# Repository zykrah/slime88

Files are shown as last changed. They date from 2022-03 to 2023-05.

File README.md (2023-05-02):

# Slime88 TKL PCB
 A F13 TKL Multi-Layout Hotswap H88-Compat Type-C PCB, designed in KiCAD 6.0.

**This board has now been prototyped! See IRL images below.**

> NOTE: Below images may be outdated.

Renders (KiCAD):





IRL images of rev1 protos:







## Features
- Fits the h88(c) standard (confirmed working in a KFE CE, should fit F13 frog)
- Uses the RP2040 MCU (new), with 16MB of external flash
- Uses Kailh Hotswap Sockets
- Added anti-shearing to the hotswap sockets
- Holes of hotswap socket holes are plated, you can still solder in a switch, should a hotswap socket ever shear off for whatever reason
- Multi-layout (see below)
- Removable USB-C connector, as well as a JST connector for [Unified Daughterboard](https://github.com/ai03-2725/Unified-Daughterboard) support (for F13 TKL boards that are compatible with the daughterboard version of the h88c)
- Has cutouts for a gummy o-ring mount (Same as the hineybush h88c pcb, for boards such as the Freebird TKL or TGR Jane V2 CE)
- BOOT pins/header for getting into bootloader (short the pins while plugging in) if [bootmagic](https://github.com/qmk/qmk_firmware/blob/master/docs/feature_bootmagic.md) isn't available . Acessible from both sides of the PCB, even when PCB is built in a keyboard. Just remove the **END key/switch** to access it.
- SWD header for debugging
- Has unused MCU GPIO pins broken out
- ESD chip (SRV05-4) to prevent damage from electrostatic discharge
- Polyfuse to prevent overcurrent
- Optimized for manufacturing and assembly with JLCPCB
- Bonus: Curved traces and teardrops

> Also, `Sleep-Lib` is just the library by [Sleepdealer](https://github.com/Sleepdealr), used in his [RP2040 Design guide](https://github.com/Sleepdealr/RP2040-designguide).

## Firmware
~~As of writing, the board runs the rp2040 branch/fork of vial-qmk. I will update this to use the official QMK implementation of RP2040 when it releases.~~ ~~UPDATE: RP2040 support has recently made it into QMK's `develop` branch. It will be fully merged to `master` by Q3 this year. Until then, the official maintainer of vial doesn't intend to merge those changes into their vial repo either, so I have made my own fork for the boards. When vial-qmk is officially updated to use QMK's implementiation of the RP2040, I will update this page once again linking to that, assuming I get the board merged into the official repo too.~~

You can find the up-to-date VIAL firmware [here](https://github.com/zykrah/vial-qmk/tree/vial-stable-zykrah/keyboards/zykrah/slime88). 

UPDATE: The board is now also in [qmk master](https://github.com/qmk/qmk_firmware/tree/master/keyboards/zykrah/slime88). (This particular version will only be VIA compatible). It should automatically be detected in VIA.



## WIP/Ideas
- Spare components on the board (i.e. diodes)
- Add physical reset switch (you currently have to short the pins on the SWD header manually)
- Add physical boot switch (you currently have to short the BOOT pins manually)
- Version with flex cuts (Already done but removed for acoustic reasons. See the board at [this point in time](https://github.com/zykrah/slime88/commit/3de3e59620d77a87f4beb085508b7e4e2e0daaf5))
- Update silkscreen graphics
- Add more layout indicators on the top silkscreen of the pcb
- Do something more special with USB shield/ground connection (currently shield is connected straight to ground)
- Move ESD chip to before fuse
- ~~Also breakout 3v3 and 5v on the pin breakout~~ Thanks [@vinorodrigues](https://github.com/vinorodrigues)!

## Multi-Layout Support

> NOTE: ANSI/ISO support works a little bit specially, either combination is soldered in at a time to ensure minimal R3 Cherry profile interference, and avoid having to rotate hotswap sockets 90 degrees to east/west orientation. See second image below.





## Removable USB C Port

Uses mousebites. Strength/functionality is untested.



## How to Manufacture the PCBs (JLCPCB)
~~I would personally use [this plugin](https://github.com/Bouni/kicad-jlcpcb-tools).~~

~~All components should be basic components, apart from the MCU, fuse, and JST connector (extended).~~

~~JLC also does have [kailh hotswap sockets](https://jlcpcb.com/parts/componentSearch?isSearch=true&searchTxt=C2803348) (extended) in its parts library, but you should be very careful with the ANSI/ISO multilayout support. In the BOM, only include either desired combination of sockets (or none of them, and hand solder in the ones you want).~~

The manufacturing files (JLCPCBA specific) have been added to the repo, you need to choose betweeen ANSI or ISO enter/pipe hotswap sockets being soldered by default.

You may want to consider generating the manufacturing files for yourself. I have not fully tested the ones that are currently in the repo.

> **NOTE: As the USB C connector is top-mounted (all other components are bottom mounted), as of writing, JLCPCB will charge extra to assemble the USB C connector (Standard assembly, both sides). You will likely have to hand solder it if you don't want to pay too much. Otherwise, seek out a proper PCB manufacturer (which will require further experience/knowledge).**

## Silkscreen
For the non-weebs, the silkscreen is based on Rimuru Tempest



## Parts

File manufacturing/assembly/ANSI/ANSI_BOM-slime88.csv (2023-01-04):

Comment | Designator | Footprint | LCSC
1k | R4,R5 | R_0402_1005Metric | C11702
JST-SH-4P | J3 | JST_SH_SM04B-SRSS-TB_1x04-1MP_P1.00mm_Horizontal | C145956
100nF | C10,C11,C12,C17,C2,C3,C6,C7,C8,C9 | C_0402_1005Metric | C1525
10uF | C4 | C_0402_1005Metric | C15525
22pF | C15,C16 | C_0402_1005Metric | C1555
USB_C | J1 | USB_C_Receptacle_HRO_TYPE-C-31-M-12 | C165948
RP2040 | U2 | RP2040-QFN-56 | C2040
27R | R2,R3 | R_0603_1608Metric | C25190
10k | R1 | R_0402_1005Metric | C25744
5.1k | R6,R7 | R_0402_1005Metric | C25905
? | SW1,SW10,SW100,SW101,SW102,SW103,SW104,SW11,SW12,SW13,SW14,SW15,SW16,SW17,SW18,SW19,SW2,SW20,SW21,SW22,SW23,SW24,SW25,SW26,SW27,SW28,SW29,SW3,SW30,SW31,SW32,SW33,SW34,SW35,SW36,SW37,SW38,SW39,SW4,SW40,SW41,SW42,SW43,SW44,SW45,SW46,SW47,SW48,SW49,SW5,SW50,SW52,SW53,SW54,SW55,SW56,SW57,SW58,SW59,SW6,SW60,SW61,SW62,SW63,SW64,SW65,SW66,SW67,SW69,SW7,SW70,SW71,SW72,SW73,SW74,SW75,SW76,SW77,SW78,SW79,SW8,SW80,SW81,SW82,SW83,SW84,SW85,SW86,SW87,SW88,SW89,SW9,SW90,SW91,SW92,SW93,SW94,SW95,SW96,SW97,SW98,SW99 | SW_MX_HS_1u | C5156480
1uF | C1,C13,C14,C5 | C_0402_1005Metric | C52923
XC6206 | U1 | SOT-23 | C5446
500mA | F1 | Fuse_1206_3216Metric | C70076
D | D1,D10,D11,D12,D13,D14,D15,D16,D17,D18,D19,D2,D20,D21,D22,D23,D24,D25,D26,D27,D28,D29,D3,D30,D31,D32,D33,D34,D35,D36,D37,D38,D39,D4,D40,D41,D42,D43,D44,D45,D46,D47,D48,D49,D5,D50,D51,D52,D53,D54,D55,D56,D57,D58,D59,D6,D60,D61,D62,D63,D64,D65,D66,D67,D68,D69,D7,D70,D71,D72,D73,D74,D75,D76,D77,D78,D79,D8,D80,D81,D82,D83,D84,D85,D86,D87,D88,D89,D9,D90,D91 | D_SOD-123 | C81598
SRV05-4 | U3 | SOT-23-6-routable | C85364
12MHz | Y1 | Crystal_SMD_3225-4Pin_3.2x2.5mm | C9002
W25Q128JVS | U4 | SOIC-8_5.23x5.23mm_P1.27mm | C97521

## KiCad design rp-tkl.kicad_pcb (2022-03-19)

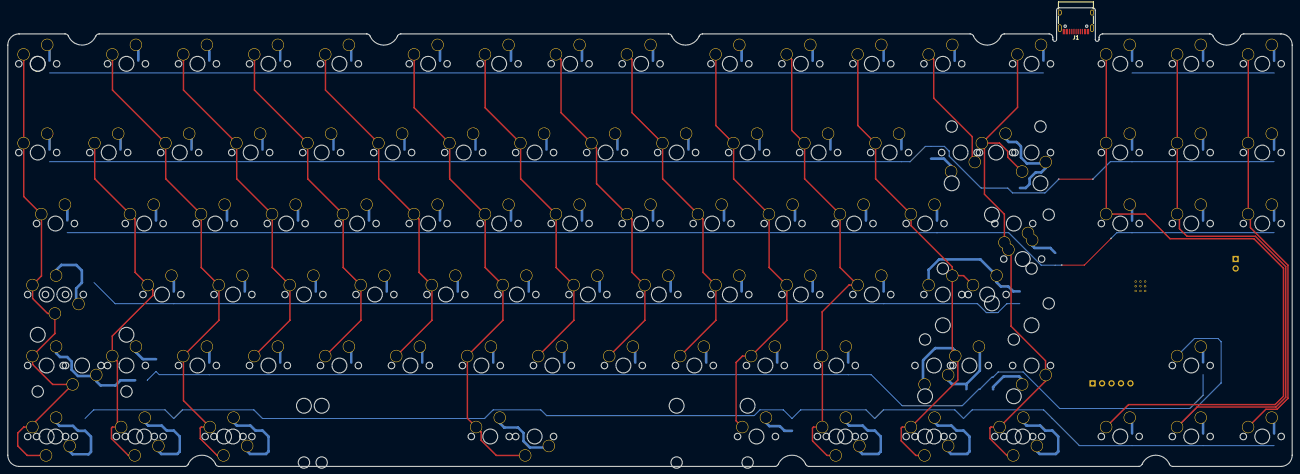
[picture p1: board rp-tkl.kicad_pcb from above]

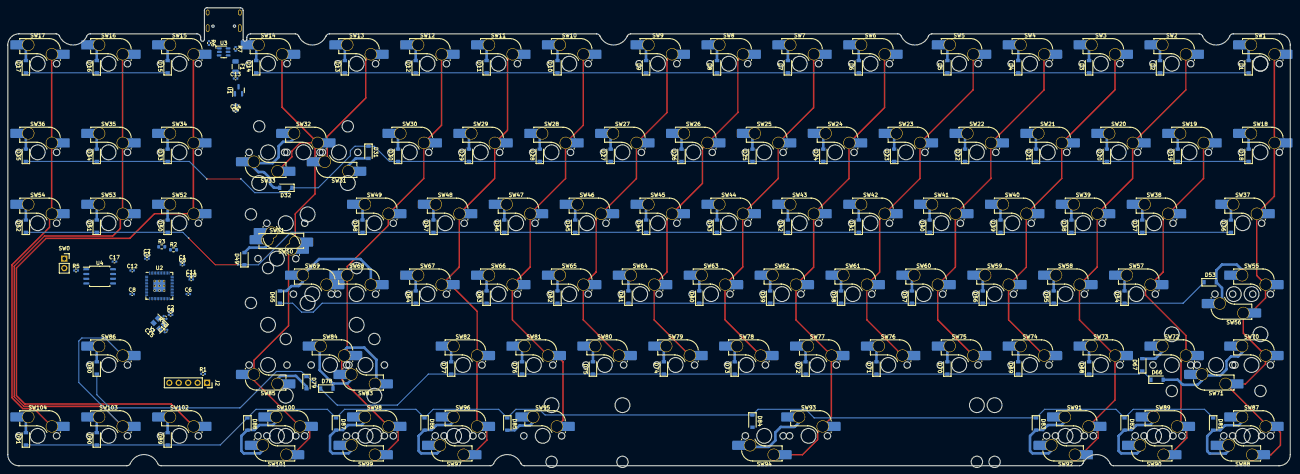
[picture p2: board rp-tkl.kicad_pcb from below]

Board: 2 copper layers, 344.7 x 123.1 mm, 235 parts (227 on the bottom side), 139 nets.

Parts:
C1, C5, C13, C14: 1uF; C_0402_1005Metric
C2, C3, C6, C7, C8, C9, C10, C11, C12, C17: 100nF; C_0402_1005Metric
C4: 10uF; C_0402_1005Metric
C15, C16: 22pF; C_0402_1005Metric
D1, D2, D3, D4, D5, D6, D7, D8, D9, D10, D11, D12, D13, D14, D15, D16, D17, D18, D19, D20, D21, D22, D23, D24, D25, D26, D27, D28, D29, D30, D31, D32, D33, D34, D35, D36, D37, D38, D39, D40, D41, D42, D43, D44, D45, D46, D47, D48, D49, D50, D51, D52, D53, D54, D55, D56, D57, D58, D59, D60, D61, D62, D63, D64, D65, D66, D67, D68, D69, D70, D71, D72, D73, D74, D75, D76, D77, D78, D79, D80, D81, D82, D83, D84, D85, D86, D87, D88, D89, D90, D91: D; D_SOD-123
F1: 500mA; Fuse_1206_3216Metric
J1: USB_C_Receptacle_USB2.0; USB_C_Receptacle_HRO_TYPE-C-31-M-12
J2: SWD; PinSocket_1x05_P2.54mm_Vertical
R1: 10k; R_0402_1005Metric
R2, R3: 27R; R_0603_1608Metric
R4, R5: 1k; R_0402_1005Metric
R6, R7: 5.1k; R_0402_1005Metric
S1: BACKSPACE; STAB_MX_2u
S2: ISO_ENTER; STAB_MX_ISO_FLIPPED
S3: ANSI_ENTER; STAB_MX_2.25u
S4: LSHIFT; STAB_MX_2.25u
S5: RSHIFT; STAB_MX_2.75u
S6: 6.25U_SPACE; STAB_MX_6.25u
S7: 7U_SPACE; STAB_MX_7u
SW0: SW_Push; PinSocket_1x02_P2.54mm_Vertical
SW1, SW2, SW3, SW4, SW5, SW6, SW7, SW8, SW9, SW10, SW11, SW12, SW13, SW14, SW15, SW16, SW17, SW18, SW19, SW20, SW21, SW22, SW23, SW24, SW25, SW26, SW27, SW28, SW29, SW30, SW31, SW32, SW33, SW34, SW35, SW36, SW38, SW39, SW40, SW41, SW42, SW43, SW44, SW45, SW46, SW47, SW48, SW49, SW51, SW52, SW53, SW54, SW57, SW58, SW59, SW60, SW61, SW62, SW63, SW64, SW65, SW66, SW67, SW68, SW69, SW71, SW72, SW73, SW74, SW75, SW76, SW77, SW78, SW79, SW80, SW81, SW82, SW84, SW85, SW86, SW90, SW93, SW94, SW98, SW102, SW103, SW104: ?; SW_MX_HS_1u
SW37, SW50, SW88, SW92, SW96, SW100: ?; SW_MX_HS_1.5u
SW55: ?; SW_MX_HS_1.75u_stp
SW56, SW83: ?; SW_MX_HS_1.75u
SW70, SW87, SW89, SW91, SW95, SW97, SW99, SW101: ?; SW_MX_HS_1.25u
U1: XC6206PxxxMR; SOT-23
U2: RP2040; RP2040-QFN-56
U3: SRV05-4; SOT-23-6-routable
U4: W25Q128JVS; SOIC-8_5.23x5.23mm_P1.27mm
Y1: 12MHz; Crystal_SMD_3225-4Pin_3.2x2.5mm

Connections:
+1V1: C1.1, C2.1, C3.1, U2.23 (DVDD), U2.50 (DVDD)
+3V3: C4.1, C5.1, C6.1, C7.1, C8.1, C9.1, C10.1, C11.1, C12.1, C14.2, C17.1, J2.2, R1.1, U1.2 (VO), U2.1 (IOVDD), U2.10 (IOVDD), U2.22 (IOVDD), U2.33 (IOVDD), U2.42 (IOVDD), U2.43 (ADC_AVDD), U2.48 (USB_VDD), U2.49 (IOVDD), U4.8 (VCC)
+5V: C13.2, F1.2, U1.3 (VI), U3.5 (VP)
/CC1: J1.A5 (CC1), R6.1
/CC2: J1.B5 (CC2), R7.1
/D_+: R2.2, U2.47 (D+)
/D_-: R3.2, U2.46 (D-)
/XTAL_O: C16.2, R4.1, Y1.1
/~USB_BOOT: R5.1, SW0.2
COL0: SW1.1, SW18.1, SW37.1, SW55.1, SW56.2, SW70.1, SW71.2, SW87.1, SW88.2
COL1: SW19.1, SW38.1, SW57.1, SW72.1, SW89.1, SW90.2
COL2: SW2.1, SW20.1, SW39.1, SW58.1, SW73.1, SW91.1, SW92.2
COL3: SW3.1, SW21.1, SW40.1, SW59.1, SW74.1
COL4: SW4.1, SW22.1, SW41.1, SW60.1, SW75.1
COL5: SW5.1, SW23.1, SW42.1, SW61.1, SW76.1
COL6: SW6.1, SW24.1, SW43.1, SW62.1, SW77.1, SW93.1, SW94.2
COL7: SW7.1, SW25.1, SW44.1, SW63.1, SW78.1
COL8: SW8.1, SW26.1, SW45.1, SW64.1, SW79.1
COL9: SW9.1, SW27.1, SW46.1, SW65.1, SW80.1
COL10: SW10.1, SW28.1, SW47.1, SW66.1, SW81.1, SW95.1
COL11: SW11.1, SW29.1, SW48.1, SW67.1, SW82.1, SW96.1, SW97.2
COL12: SW12.1, SW30.1, SW49.1, SW68.2, SW69.1, SW83.2, SW84.1, SW98.1, SW99.2
COL13: SW13.1, SW31.1
COL14: SW14.1, SW32.1, SW33.2, SW50.2, SW51.1, SW85.1, SW100.1, SW101.2
COL15: SW15.1, SW34.1, SW52.1, SW102.1
COL16: SW16.1, SW35.1, SW53.1, SW86.1, SW103.1
COL17: SW17.1, SW36.1, SW54.1, SW104.1
CS: R5.2, U2.56 (QSPI_SS_N), U4.1 (~CS)
DBUS+: J1.A6 (D+), J1.B6 (D+), R2.1, U3.4 (IO3)
DBUS-: J1.A7 (D-), J1.B7 (D-), R3.1, U3.3 (IO2)
GND: C1.2, C2.2, C3.2, C4.2, C5.2, C6.2, C7.2, C8.2, C9.2, C10.2, C11.2, C12.2, C13.1, C14.1, C15.1, C16.1, C17.2, J1.A1 (GND), J1.A12 (GND), J1.B1 (GND), J1.B12 (GND), J1.S1 (SHIELD), J2.3, R6.2, R7.2, SW0.1, U1.1 (GND), U2.19 (TESTEN), U2.57 (GND), U3.2 (VN), U4.4 (GND), Y1.2, Y1.4
unnamed: D1.2 (A), SW1.2
unnamed: D2.2 (A), SW2.2
unnamed: D3.2 (A), SW3.2
unnamed: D4.2 (A), SW4.2
unnamed: D5.2 (A), SW5.2
unnamed: D6.2 (A), SW6.2
unnamed: D7.2 (A), SW7.2
unnamed: D8.2 (A), SW8.2
unnamed: D9.2 (A), SW9.2
unnamed: D10.2 (A), SW10.2
unnamed: D11.2 (A), SW11.2
unnamed: D12.2 (A), SW12.2
unnamed: D13.2 (A), SW13.2
unnamed: D14.2 (A), SW14.2
unnamed: D15.2 (A), SW15.2
unnamed: D16.2 (A), SW16.2
unnamed: D17.2 (A), SW17.2
unnamed: D18.2 (A), SW18.2
unnamed: D19.2 (A), SW19.2
unnamed: D20.2 (A), SW20.2
unnamed: D21.2 (A), SW21.2
unnamed: D22.2 (A), SW22.2
unnamed: D23.2 (A), SW23.2
unnamed: D24.2 (A), SW24.2
unnamed: D25.2 (A), SW25.2
unnamed: D26.2 (A), SW26.2
unnamed: D27.2 (A), SW27.2
unnamed: D28.2 (A), SW28.2
unnamed: D29.2 (A), SW29.2
unnamed: D30.2 (A), SW30.2
unnamed: D31.2 (A), SW31.2
unnamed: D32.2 (A), SW32.2, SW33.1
unnamed: D33.2 (A), SW34.2
unnamed: D34.2 (A), SW35.2
unnamed: D35.2 (A), SW36.2
unnamed: D36.2 (A), SW37.2
unnamed: D37.2 (A), SW38.2
unnamed: D38.2 (A), SW39.2
unnamed: D39.2 (A), SW40.2
unnamed: D40.2 (A), SW41.2
unnamed: D41.2 (A), SW42.2
unnamed: D42.2 (A), SW43.2
unnamed: D43.2 (A), SW44.2
unnamed: D44.2 (A), SW45.2
unnamed: D45.2 (A), SW46.2
unnamed: D46.2 (A), SW47.2
unnamed: D47.2 (A), SW48.2
unnamed: D48.2 (A), SW49.2
unnamed: D49.2 (A), SW50.1, SW51.2
unnamed: D50.2 (A), SW52.2
unnamed: D51.2 (A), SW53.2
unnamed: D52.2 (A), SW54.2
unnamed: D53.2 (A), SW55.2, SW56.1
unnamed: D54.2 (A), SW57.2
unnamed: D55.2 (A), SW58.2
unnamed: D56.2 (A), SW59.2
unnamed: D57.2 (A), SW60.2
unnamed: D58.2 (A), SW61.2
unnamed: D59.2 (A), SW62.2
unnamed: D60.2 (A), SW63.2
unnamed: D61.2 (A), SW64.2
unnamed: D62.2 (A), SW65.2
unnamed: D63.2 (A), SW66.2
unnamed: D64.2 (A), SW67.2
unnamed: D65.2 (A), SW68.1, SW69.2
unnamed: D66.2 (A), SW70.2, SW71.1
unnamed: D67.2 (A), SW72.2
unnamed: D68.2 (A), SW73.2
unnamed: D69.2 (A), SW74.2
unnamed: D70.2 (A), SW75.2
unnamed: D71.2 (A), SW76.2
unnamed: D72.2 (A), SW77.2
unnamed: D73.2 (A), SW78.2
unnamed: D74.2 (A), SW79.2
unnamed: D75.2 (A), SW80.2
unnamed: D76.2 (A), SW81.2
unnamed: D77.2 (A), SW82.2
unnamed: D78.2 (A), SW83.1, SW84.2
unnamed: D79.2 (A), SW85.2
unnamed: D80.2 (A), SW86.2
unnamed: D81.2 (A), SW87.2, SW88.1
unnamed: D82.2 (A), SW89.2, SW90.1
unnamed: D83.2 (A), SW91.2, SW92.1
unnamed: D84.2 (A), SW93.2, SW94.1
unnamed: D85.2 (A), SW95.2
unnamed: D86.2 (A), SW96.2, SW97.1
unnamed: D87.2 (A), SW98.2, SW99.1
unnamed: D88.2 (A), SW100.2, SW101.1
unnamed: D89.2 (A), SW102.2
unnamed: D90.2 (A), SW103.2
unnamed: D91.2 (A), SW104.2
QSPI_CLK: U2.52 (QSPI_SCLK), U4.6 (CLK)
ROW0: D1.1 (K), D2.1 (K), D3.1 (K), D4.1 (K), D5.1 (K), D6.1 (K), D7.1 (K), D8.1 (K), D9.1 (K), D10.1 (K), D11.1 (K), D12.1 (K), D13.1 (K), D14.1 (K), D15.1 (K), D16.1 (K), D17.1 (K)
ROW1: D18.1 (K), D19.1 (K), D20.1 (K), D21.1 (K), D22.1 (K), D23.1 (K), D24.1 (K), D25.1 (K), D26.1 (K), D27.1 (K), D28.1 (K), D29.1 (K), D30.1 (K), D31.1 (K), D32.1 (K), D33.1 (K), D34.1 (K), D35.1 (K)
ROW2: D36.1 (K), D37.1 (K), D38.1 (K), D39.1 (K), D40.1 (K), D41.1 (K), D42.1 (K), D43.1 (K), D44.1 (K), D45.1 (K), D46.1 (K), D47.1 (K), D48.1 (K), D49.1 (K), D50.1 (K), D51.1 (K), D52.1 (K)
ROW3: D53.1 (K), D54.1 (K), D55.1 (K), D56.1 (K), D57.1 (K), D58.1 (K), D59.1 (K), D60.1 (K), D61.1 (K), D62.1 (K), D63.1 (K), D64.1 (K), D65.1 (K)
ROW4: D66.1 (K), D67.1 (K), D68.1 (K), D69.1 (K), D70.1 (K), D71.1 (K), D72.1 (K), D73.1 (K), D74.1 (K), D75.1 (K), D76.1 (K), D77.1 (K), D78.1 (K), D79.1 (K), D80.1 (K)
ROW5: D81.1 (K), D82.1 (K), D83.1 (K), D84.1 (K), D85.1 (K), D86.1 (K), D87.1 (K), D88.1 (K), D89.1 (K), D90.1 (K), D91.1 (K)
SD0: U2.53 (QSPI_SD0), U4.5 (DI(IO0))
SD1: U2.55 (QSPI_SD1), U4.2 (DO(IO1))
SD2: U2.54 (QSPI_SD2), U4.3 (IO2)
SD3: U2.51 (QSPI_SD3), U4.7 (IO3)
SWCLK: J2.5, U2.24 (SWCLK)
SWD: J2.4, U2.25 (SWDIO)
VBUS: F1.1, J1.A4 (VBUS), J1.A9 (VBUS), J1.B4 (VBUS), J1.B9 (VBUS)
XTAL_IN: C15.2, U2.20 (XTAL_IN), Y1.3
XTAL_OUT: R4.2, U2.21 (XTAL_OUT)
~RESET: J2.1, R1.2, U2.26 (~RUN)

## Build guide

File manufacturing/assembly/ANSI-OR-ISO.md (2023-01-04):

# DIFFERENCE BETWEEN ANSIO AND ISO

If you read the main README in the root directory, you would see that there's two options for the ANSI/ISO cluster. You cannot have both sets of hotswap sockets on at the same time. For that reason, I have created two separate BOM/CPL files for either option to be assembled by default.

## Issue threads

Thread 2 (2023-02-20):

S1 UDB support

JarTheHead, 2023-02-20:
Suggestion for a future revision to support the new [S1 daughterboard](https://github.com/Unified-Daughterboard/UDB-S) with the Pico-EZmate connector.

zykrah, 2023-02-20:
You can fork and modify as required, should require just changing the footprint to the ezmate connector and rerouting slightly.

Otherwise I'll upload the changes in a separate branch when I have some time.

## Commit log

2022-03-19 KiCAD project initialization
    [rp-tkl.kicad_pcb, rp-tkl.kicad_sch]
2022-03-19 Added RP2040 libraries
    Courtesy of https://github.com/Sleepdealr/RP2040-designguide
    [RP2040_QFN_PACKAGE.STEP]
2022-03-19 Added main component symbols and PCB Outline
    [rp-tkl.kicad_pcb, rp-tkl.kicad_sch]
2022-03-19 Finished most of preliminary schematic
    [rp-tkl.kicad_sch]
2022-03-19 Added Footprint Libs, Annotated schematic, Imported footprints
    [rp-tkl.kicad_pcb, rp-tkl.kicad_sch]
2022-03-19 [Excluding Switches] Moved components to rough positions on pcb
    Also added 5 pin programming header
    [rp-tkl.kicad_pcb, rp-tkl.kicad_sch]
2022-03-19 [Preliminary] Added Switch matrix and imported footprints
    [matrix.kicad_sch, rp-tkl.kicad_pcb, rp-tkl.kicad_sch]
2022-03-19 Added Stabilizers
    [matrix.kicad_sch, rp-tkl.kicad_pcb, rp-tkl.kicad_sch]
2022-03-19 All switches (not diodes) in position
    [matrix.kicad_sch, rp-tkl.kicad_pcb, rp-tkl.kicad_sch]
2022-03-19 [Preliminary] Positioned diodes
    [rp-tkl.kicad_pcb]
2022-03-19 Changed Diodes to sod123
    [matrix.kicad_sch, rp-tkl.kicad_sch]
2022-03-19 Fixed some 3D models not showing
    [rp-tkl.kicad_pcb]
2022-03-19 [Preliminary] Matrix routed
    [rp-tkl.kicad_pcb]
2022-03-19 Further work on routing
    Added GND fills, wired USB more
    Need to do:
    MCU area
    [matrix.kicad_sch, rp-tkl.kicad_sch]
2022-03-22 [Preliminary] Completed MCU Routing
    - Also added some small things that i forgot on schematic
    - Need to: connect matrix to mcu
    [rp-tkl.kicad_sch]
2022-03-22 [Preliminary] Traced rough estimate of how rows and columns will connect to pins
2022-03-22 [Preliminary] Completed all routing
    [rp-tkl.kicad_sch]
2022-03-24 [70% Done] Rounded all traces
2022-03-25 [99% Done] Trace rounding and cleanup
2022-03-31 Added JST Connector
    Also cleaned up everything, 99% done
    [rp-tkl.kicad_sch]
2022-03-31 More cleanup, added connector for/broke out unused pins
    [rp-tkl.kicad_sch]
2022-03-31 More minor changes
    Added a ground pad to the unused pin breakout
2022-03-31 Cleaned up silkscreen and fab layers
    Also adjusted some of the component descriptions/names
    [rp-tkl.kicad_sch]
2022-04-02 [Big changes] Added flex cuts and changed switch matrix/ pinout
    - Optimized switch matrix by changing how the split backspace is done. It now connects to a different row instead of creating a whole different column
    - Shifted a lot of traces/pins over by one, slight retracing work around the mcu area
    - Added one more pin to the unused pins header
    - Added 2 simple flex cuts
    - Slight shifting around of different diodes
    - Added 3d model for JST and USB-C Connector
    - Extended bottom of the pcb by 0.5mm to accommodate for stab holes a bit better.
    [matrix.kicad_sch, rp-tkl.kicad_sch]
2022-04-03 Changed position of upper flex cut
    Didn't remove the old traces yet
2022-04-14 Lots of minor changes (some important changes)
    - Re-routed a lot of traces to the left of MCU
    - changed the rounding of some traces
    - changed the layout and rotation of some of the switch footprints/stabilizers to better reflect h88c
    - [IMPORTANT] changed minimum via size to 0.3/0.6 as per JLC spec
    - added bunch of random vias to via stitch GND fills
2022-04-17 Removed flex cut, updated outline and usb placement
    Also:
    - updated plugin config
    - changed pullup resistor placement and routing of some of the switch matrix (moved down row traces)
    - changed around some routing of the decoupling caps
    - added more stitching vias
2022-04-20 DRC fixes
    - changed the layer of the dimensions (they were on B.Cu before)
    - fixed some vias which were still 0.2/0.4
    - fixed some traces slightly too close to eachother
    - fixed some silkscreens
2022-04-20 Added some anti-shear vias
    (not intended for PCB assembly)
2022-04-20 Added traces to the anti-shear (on the front)
    Just for aesthetics
2022-04-29 Added mousebites to USB connector, some rerouting
    - Added mousebites next to the USB c connector area so the USB port is now more easily removeable.
    - Rerouted some of the USB area as a result of the above change
    - Modified USB silkscreen a bit (removed some lines)
    - Changed minimum trace width
    - Updated ESC and TILDE footprints to have a shorter pad so it doesn't go off the edge of the pcb. Did something similar for the F13 key because it was a bit close to the mousebites
2022-04-30 Fixed antishear vias, added multi-layout markings to silkscreen
    - Fixed the anti-shear vias (they were too small before; from 0.2/0.4 to 0.3/0.6)
    - Added some basic silkscreen to mark multi-layouts
2022-04-30 Fixed 3D models
    - hid the ISO hotswap socket 3d models
    - added all missing 3d models
2022-04-30 Minor changes to column traces
2022-05-27 Changed 1v1, Added silkscreen graphics
    - Named board Slime88
    - Changed internal 1v1 tracing a little bit
    - Added front and back graphics (stolen from one of my older boards)
    - Added RP logo and QMK badge
    - Added silkscreen labels to the pin breakout, SWD and boot pins.
    - :peepoSmile:
2022-05-29 Renamed KiCAD project to slime88
    weeb
    [slime88.kicad_sch]
2022-05-29 Update README.md
    Credited Sleepdealr for RP2040 footprint/symbol library.
2022-05-29 Updated PCB silkscreen, gitignore, README
    Added github link to pcb silkscreen (on the back)
2022-05-29 Updated BOM inclusions
    [matrix.kicad_sch, slime88.kicad_sch]
2022-05-30 Broke out 3v3 and 5v on Pin Breakout
    Suggested by https://github.com/vinorodrigues
    Slightly changed silkscreen (SWD -> SWDIO, Added boot indicator on the top silk)
    Rewired some of the matrix to appropriately fit the 3v3 and 5v traces.
    [slime88.kicad_sch]
2022-05-30 Minor shift of gnd vias
2023-01-04 Generated manufacturing files (JLC), Updated Sleep-lib to a submodule, updated manufacturing files/part numbers
    [ANSI_BOM-slime88.csv, ISO_BOM-slime88.csv, RP2040_QFN_PACKAGE.STEP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]
